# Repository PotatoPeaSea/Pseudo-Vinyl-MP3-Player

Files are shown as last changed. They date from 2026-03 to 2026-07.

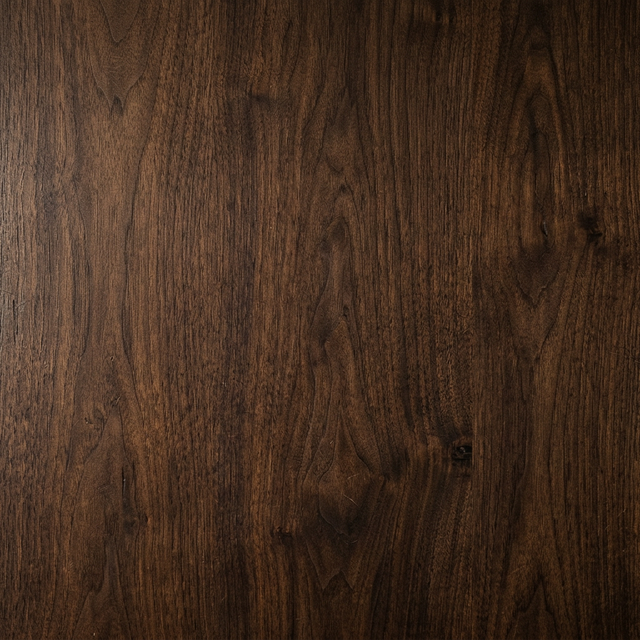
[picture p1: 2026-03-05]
tools/prescale_art/wood_bg.png

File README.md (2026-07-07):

# Pseudo Vinyl MP3 Player

A portable, battery-powered MP3 player built on the **ESP32-WROOM-32** that streams audio wirelessly to Bluetooth earbuds and features a **vinyl-style spinning album art** animation on a circular display.





> [!NOTE]
> **Why the classic ESP32 and not the S3?** The project originally targeted the ESP32-S3, but the S3 only has BLE — **no Bluetooth Classic**, which A2DP audio streaming requires. The original ESP32 is the only chip in the family that can act as an A2DP source. The trade-off is that the WROOM-32 has no PSRAM, which shapes several architecture decisions below.

## Features

- **Bluetooth Audio** — Streams to wireless earbuds/speakers via A2DP (primary output), with on-device scanning, pairing, and auto-reconnect
- **Wired Output** — Secondary 3.5mm headphone jack via PCM5102 I2S DAC, switchable in Settings
- **Circular Display** — 1.28" GC9A01 240×240 IPS round screen
- **Vinyl Spin Animation** — Album art spins like a vinyl record during playback, with a progress ring around the display edge
- **Physical Controls** — 3 buttons (play/pause, next, previous) + rotary encoder (volume/scroll)
- **Shuffle & Repeat** — Normal / Shuffle / Repeat All / Repeat One, cycled via encoder push
- **SD Card Storage** — Recursively scans a FAT32 SD card for MP3s
- **Persistent Settings** — Output mode, volume, and paired Bluetooth device survive power cycles (NVS)
- **Battery Powered** — LiPo battery with TP4056 USB-C charging

## Documentation

| Document | Contents |
|---|---|
| [User Guide](docs/USER_GUIDE.md) | Getting started, controls, pairing, troubleshooting |
| [PRD](docs/PRD.md) | Full requirements, pin assignments, risks |
| This README | System architecture, build instructions |

---

## Hardware

| Component | Model | Interface |
|---|---|---|
| MCU | ESP32-WROOM-32 (4MB flash, no PSRAM) | — |
| DAC | PCM5102 | I2S |
| Display | GC9A01 1.28" Round IPS, 240×240 | SPI (VSPI) |
| Storage | SPI SD card reader, FAT32 | SPI (HSPI) |
| Encoder | KY-040 rotary encoder | GPIO |
| Buttons | 3× tactile switches | GPIO |
| Battery | 3.7V LiPo + TP4056 USB-C charger | — |

### Wiring

Full pin table with rationale lives in the [PRD §5](docs/PRD.md) and [`firmware/src/config.h`](firmware/src/config.h). Summary:

| Peripheral | Pins |
|---|---|
| Display (VSPI) | SCK 18, MOSI 23, CS 5, DC 2, RST 4, BL 19 |
| SD card (HSPI) | SCK 14, MOSI 13, MISO 35, CS 15 |
| PCM5102 (I2S) | BCK 26, LRCK 25, DIN 22 |
| Encoder | CLK 32, DT 33, SW 27 |
| Buttons | Play 16, Next 17, Prev 21 |
| Battery sense | GPIO 34 (ADC1) |

Three wiring rules worth knowing (all enforced by this pin map):

1. **GPIO 12 is deliberately unused.** Many SD modules have pull-ups on every line; a pull-up on GPIO 12 at boot selects 1.8V flash voltage and the board won't boot.
2. **Battery sense must be on ADC1** (GPIO 32–39). ADC2 is unusable while Bluetooth is running.
3. **Display and SD are on separate hardware SPI buses** (VSPI/HSPI), so display refresh never blocks audio streaming from the card.

---

## System Architecture

### Module layout

```
firmware/src/
├── main.cpp                  # Boot sequence + FreeRTOS tasks + input routing
├── config.h                  # All pins, buffer sizes, tunables
├── audio/audio_manager.*     # MP3 decode (helix), playlist, output routing
├── bluetooth/bt_manager.*    # A2DP source, discovery, PCM ring buffer, NVS
├── display/display_manager.* # TFT_eSPI + LVGL glue, draw buffers
├── display/ui_manager.*      # All LVGL screens, virtual keypad, album art
├── input/input_manager.*     # Debounced buttons + quadrature encoder ISR
└── storage/sd_manager.*      # SD mount, recursive MP3 scan, .art loading
```

Each module is a namespace with a small public API (`AudioMgr::`, `BtMgr::`, `UI::`, …); `main.cpp` is the only place that wires them together.

### Task model (dual-core FreeRTOS)

```mermaid
graph LR
    subgraph Core 0
        BT["BT Classic stack<br/>(ESP-IDF tasks)"]
        AUDIO["audio task (prio 3)<br/>SD read → helix MP3 decode<br/>→ volume → output"]
    end
    subgraph Core 1
        UI["ui task (prio 1)<br/>LVGL refresh @ ~60Hz<br/>vinyl spin, BT status sync"]
        INPUT["input task (prio 2)<br/>5ms poll, debounce,<br/>event routing"]
    end
    AUDIO -- "PCM ring buffer (16KB)" --> BT
    INPUT -- "LVGL keys / AudioMgr calls" --> UI
```

- **Audio task (core 0)** runs the decode loop: one `StreamCopy` step per iteration reads MP3 bytes from SD, decodes via helix, applies volume, and writes PCM to the active output. It shares core 0 with the Bluetooth stack on purpose — the 16KB ring buffer between them absorbs scheduling jitter.
- **UI task (core 1)** drives LVGL: syncs now-playing state, spins the vinyl, and polls Bluetooth state a few times per second (not every frame).
- **Input task (core 1)** polls buttons/encoder every 5ms with 50ms debounce and routes events based on the active screen.

### Audio pipeline

```
                         ┌──────────────── audio task ────────────────┐
SD card ──> MP3 file ──> StreamCopy ──> helix MP3 decoder ──> meter ──> VolumeStream ──┐
                                                                                       │ (runtime switch)
                             ┌─────────────────────────────────────────────────────────┤
                             ▼                                                         ▼
                      I2SStream (wired)                                      BtPrint → ring buffer
                             │                                                         │ (pulled by BT task)
                             ▼                                                         ▼
                      PCM5102 DAC → 3.5mm                                    A2DP source → earbuds
```

Key decisions:

- **helix MP3 (arduino-audio-tools)** instead of ESP32-audioI2S: the latter requires PSRAM as of v3.x, which the WROOM-32 doesn't have. Helix decodes in ~30KB of SRAM.
- **Output switching** re-routes the tail of the pipeline at runtime (Settings → Output). Wired mode stops the A2DP source entirely; Bluetooth mode stops the I2S driver.
- **Position/duration** are derived, not parsed: position = decoded PCM bytes ÷ byte rate; duration = position × file size ÷ compressed bytes consumed (exact for CBR, converges fast for VBR).
- **In BT mode with no sink connected, playback holds** rather than racing through the file while writes are dropped.
- A2DP is fixed at 44.1kHz — MP3s at other sample rates play off-speed over Bluetooth (fine on wired).

### Bluetooth design

`BtMgr` wraps `BluetoothA2DPSource` (pschatzmann/ESP32-A2DP):

- While unconnected, the library continuously discovers nearby A2DP sinks; every device seen is collected for the UI list.
- Selecting a device sets it as the **target** — the next discovery hit on that name connects, and the name is persisted to NVS so the player auto-reconnects on later boots.
- The BT stack pulls PCM from the ring buffer on its own task; underruns are zero-filled so the stream never stalls.

### Display & UI

- **TFT_eSPI** drives the GC9A01 at 40MHz on VSPI; **LVGL 8** renders into two 240×30 draw buffers (~14.4KB each) in internal DMA-capable RAM.
- `LV_COLOR_16_SWAP=1` produces SPI byte order directly, so the flush callback pushes pixels without a per-frame swap.
- **Navigation without a touchscreen:** a virtual LVGL *keypad* input device. The input task translates encoder turns into `LV_KEY_NEXT/PREV` (focus movement) and the Play button into `LV_KEY_ENTER` (select) whenever a menu screen is active. Each screen has its own LVGL focus group.
- **Album art** is a pre-scaled raw RGB565 file (`.art`) loaded once per track change, displayed inside a circle-clipped, rotating holder. See the art tool below.

### Memory budget (the no-PSRAM constraint)

Everything must fit in ~320KB of usable internal SRAM:

| Consumer | ~Size |
|---|---|
| BT Classic stack (controller + Bluedroid) | ~150KB |
| LVGL draw buffers (2 × 240×30 px) | 29KB |
| Album art (≤120×120 RGB565, capped) | ≤29KB |
| helix MP3 decoder | ~30KB |
| BT PCM ring buffer | 16KB |
| LVGL widgets, task stacks, everything else | remainder |

This is why art is capped at 120×120 (`ART_MAX_SIDE`) — a full 240×240 frame would be 113KB and simply doesn't fit next to the BT stack. Measured at build: **18.4% static RAM, 52.8% flash**.

---

## Building the Firmware

Requires [PlatformIO](https://platformio.org/).

```bash
cd firmware
pio run                 # build
pio run -t upload       # flash over USB
pio device monitor      # serial log @ 115200
```

The environment is `esp32dev` (see [`firmware/platformio.ini`](firmware/platformio.ini)). Libraries: TFT_eSPI, LVGL 8.3, arduino-audio-tools, arduino-libhelix, ESP32-A2DP. The 3MB `huge_app` partition is used (no OTA) because BT Classic + LVGL + codecs don't fit the default scheme.

## Album Art Pre-Scaler Tool

MP3 album art is prepared on your PC before copying music to the SD card — the device never decodes JPEG/PNG.

```bash
cd tools/prescale_art
pip install -r requirements.txt
python prescale_art.py /path/to/music
```

For each `song.mp3` with embedded art, this writes `song.art` alongside it: a raw 120×120 RGB565 bitmap (28,800 bytes, big-endian to match the firmware's `LV_COLOR_16_SWAP`). A GUI version (`prescale_art_gui.py`) is also available. Files larger than 120×120 are rejected by the firmware.

## Project Structure

```
Pseudo-Vinyl-MP3-Player/
├── README.md                # This file — architecture + build guide
├── docs/
│   ├── PRD.md               # Product Requirements Document
│   └── USER_GUIDE.md        # End-user guide (controls, pairing, troubleshooting)
├── firmware/                # PlatformIO project (ESP32-WROOM-32)
│   ├── platformio.ini
│   └── src/                 # Modules described above
├── tools/
│   └── prescale_art/        # Album art pre-scaler (CLI + GUI)
└── MP3PlayerPCB/            # KiCad PCB design (Phase 3)
```

## License

TBD

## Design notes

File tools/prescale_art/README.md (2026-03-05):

# Album Art Pre-Scaler

Extracts embedded album art from MP3 files, resizes to 240×240 pixels, and converts to **RGB565 raw bitmap** (`.art`) for direct loading on the ESP32-S3 GC9A01 circular display.

## Setup

```bash
cd tools/prescale_art
pip install -r requirements.txt
```

## Usage

```bash
# Basic — process all MP3s in a folder (recursive), output RGB565 .art files
python prescale_art.py /path/to/music

# Force re-process everything (ignore existing .art files)
python prescale_art.py /path/to/music --force

# Output as compressed JPEG instead of raw RGB565
python prescale_art.py /path/to/music --format jpeg --quality 85
```

## Output Formats

| Format | Extension | Size per file | ESP32 Load Time | Notes |
|---|---|---|---|---|
| **RGB565** (default) | `.art` | 115,200 bytes | Fast (no decode) | Raw pixel data, direct DMA to display |
| **JPEG** | `.art.jpg` | ~5-15 KB | Slower (decode needed) | Saves SD card space, requires JPEG decoder on device |

## How It Works

1. Recursively finds all `.mp3` files
2. Extracts the first embedded `APIC` (album art) frame from ID3v2 tags
3. Center-crops to square, then resizes to 240×240 using Lanczos resampling
4. Converts to RGB565 (16-bit, big-endian — matches GC9A01 native byte order)
5. Saves as `<songname>.art` alongside the original MP3
6. Skips files where the `.art` is already newer than the `.mp3`

## File Placement

Place your `.art` files on the SD card **alongside** the MP3s:

```
SD Card/
├── Artist/
│   ├── song1.mp3
│   ├── song1.art      ← generated
│   ├── song2.mp3
│   └── song2.art      ← generated
```

The firmware will look for `<filename>.art` when loading album art for playback.

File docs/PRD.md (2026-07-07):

# Product Requirements Document: ESP32 Portable MP3 Player

**Version:** 3.0  
**Last Updated:** 2026-07-06

> [!NOTE]
> **v3.0 board change:** Moved from ESP32-S3 to the **classic ESP32-WROOM-32**. The S3 has no Bluetooth Classic (BLE only), so the A2DP requirements (§3.4) were unimplementable on it — only the original ESP32 can act as an A2DP source. Trade-off: the WROOM-32 has **no PSRAM**, which drives the memory budget in §4.

---

## 1. Product Overview

A battery-powered, handheld MP3 player built around the **ESP32-WROOM-32**. The device reads MP3 files from an SD card, displays a UI on a circular screen, and primarily streams audio wirelessly via **Bluetooth A2DP** to earbuds/speakers, with a secondary wired output option via the PCM5102 DAC. A signature visual feature is a **vinyl-style spinning album art** animation during playback.

### Development Phases

| Phase | Description |
|---|---|
| **Phase 1 — Prototyping** | Test all modules on an ESP32-WROOM-32 dev board with breadboard wiring |
| **Phase 2 — Firmware** | Develop and stabilize firmware on the dev board |
| **Phase 3 — PCB Design** | Design a custom PCB integrating all components |
| **Phase 4 — Enclosure** | 3D print an enclosure for the final assembly |

---

## 2. Hardware Bill of Materials

| Component | Model | Interface | Key Specs |
|---|---|---|---|
| MCU | ESP32-WROOM-32 | — | Dual-core LX6 @ 240 MHz, **4 MB Flash, no PSRAM**, 520 KB SRAM, **BT Classic (A2DP!)** + BLE + WiFi |
| DAC | PCM5102 | I2S | 32-bit, up to 384 kHz, 112 dB SNR, 3.5 mm jack (secondary output) |
| Display | GC9A01 1.28" Round | SPI | 240×240 px, IPS TFT, 65K color, 3.3V |
| Storage | SPI SD Card Reader | SPI | FAT32, stores MP3 files + pre-scaled album art |
| Input — Dial | KY-040 Rotary Encoder | GPIO (2 data + 1 button) | Quadrature output, integrated push-button |
| Input — Buttons | 3× Tactile Buttons | GPIO | Select/Play, Next, Previous |
| Battery | 3.7V LiPo Cell | — | Capacity TBD based on enclosure size |
| Charger | TP4056 Module | — | 1A USB-C LiPo charging with protection |
| Power Control | SPDT Slide Switch | — | Hard power-off between battery and system |

> [!IMPORTANT]
> **SPI Buses:** The GC9A01 display runs on **VSPI** and the SD card reader on **HSPI** — two independent hardware buses, so no bus-sharing mutex is needed and display refresh can't stall audio reads.

---

## 3. Functional Requirements

### 3.1 Audio Playback

| ID | Requirement | Priority |
|---|---|---|
| AUD-01 | Decode and play MP3 files (CBR and VBR, 128–320 kbps) from SD card | Must |
| AUD-02 | **Default output:** Stream decoded audio via Bluetooth A2DP (SBC codec) to paired wireless earbuds/speakers | Must |
| AUD-03 | **Secondary output:** Output decoded audio via I2S to the PCM5102 DAC for wired 3.5 mm headphone output | Must |
| AUD-04 | User-selectable audio output mode (BT or Wired) via a **Settings menu** option. Bluetooth is default on boot | Must |
| AUD-05 | Support 44.1 kHz / 16-bit stereo as the primary audio format | Must |
| AUD-06 | Gapless playback between tracks | Should |
| AUD-07 | Resume playback from last position after power cycle | Could |

### 3.2 User Interface & Display

| ID | Requirement | Priority |
|---|---|---|
| UI-01 | **Song List Screen:** Scrollable list of songs showing title (from ID3 tag or filename). Menu entries for Bluetooth and Settings at the top | Must |
| UI-02 | **Now Playing Screen:** Song title, artist, and spinning album art. Playback mode indicator (shuffle/repeat) | Must |
| UI-03 | **Vinyl Spin Animation:** Album art rendered as a circle and continuously rotated (~33 RPM) to simulate a spinning record | Must |
| UI-04 | **Bluetooth Menu Screen:** Scan for devices, show available sinks, pair/connect/disconnect | Must |
| UI-05 | **Settings Menu Screen:** Audio output toggle (BT/Wired), and future settings | Must |
| UI-06 | **Volume Indicator:** On-screen overlay that appears when volume is adjusted via encoder | Should |
| UI-07 | **Playback Progress:** Ring around the outer edge of the display showing track progress | Should |
| UI-08 | Smooth transitions between screens (slide or fade) | Could |
| UI-09 | Display should dim/sleep after inactivity to save battery; wake on any input | Should |

### 3.3 Input Controls

| ID | Requirement | Priority |
|---|---|---|
| INP-01 | **Button 1 (Select/Play):** Short press = play/pause on Now Playing, select/enter in menus | Must |
| INP-02 | **Button 2 (Next):** Short press = next track; long press = fast-forward seek | Must |
| INP-03 | **Button 3 (Previous):** Short press = previous track (restart if >3s in); long press = rewind seek | Must |
| INP-04 | **Rotary Encoder Rotation:** Adjust volume (CW = up, CCW = down) on Now Playing; scroll list in menus | Must |
| INP-05 | **Rotary Encoder Push (Now Playing):** Cycle playback mode: Normal → Shuffle → Repeat All → Repeat One → Normal | Must |
| INP-06 | **Rotary Encoder Push (Menus):** Navigate back to previous screen | Must |
| INP-07 | All buttons should be software-debounced (≥30 ms) | Must |

### 3.4 Bluetooth

| ID | Requirement | Priority |
|---|---|---|
| BT-01 | Act as A2DP **Source** — stream audio to Bluetooth headphones/speakers | Must |
| BT-02 | Scan for nearby A2DP sink devices and display results on screen | Must |
| BT-03 | Support pairing and bonding (remember paired devices across reboots via NVS) | Must |
| BT-04 | Auto-reconnect to last paired device on boot (when BT mode is active) | Must |
| BT-05 | AVRCP support (volume sync, play/pause/next/prev remote control from earbuds) | Should |
| BT-06 | Display Bluetooth connection status icon on all screens | Should |

### 3.5 SD Card & File System

| ID | Requirement | Priority |
|---|---|---|
| SD-01 | Read FAT32-formatted SD cards (up to 32 GB) | Must |
| SD-02 | Scan for `.mp3` files recursively in all directories | Must |
| SD-03 | Parse ID3v2 tags for title, artist, album | Must |
| SD-04 | Load **pre-scaled album art** from companion `.art` or `.jpg` files placed alongside MP3s by the desktop tool (see §3.6) | Must |
| SD-05 | Fallback: if no pre-scaled art file exists, display a default/generic album art image | Must |
| SD-06 | Graceful handling of missing/corrupt tags — fall back to filename | Must |
| SD-07 | Support alphabetical and folder-based sorting | Should |
| SD-08 | Cache file list and metadata index to SD card to avoid re-scanning on every boot | Should |

### 3.6 Desktop Album Art Pre-Scaler Tool

| ID | Requirement | Priority |
|---|---|---|
| TOOL-01 | Python CLI tool that processes a directory of MP3 files | Must |
| TOOL-02 | Extract embedded album art (JPEG/PNG) from ID3v2 APIC frames | Must |
| TOOL-03 | Resize and crop to 120×120 pixels (RAM cap on the no-PSRAM WROOM-32), circular mask optional | Must |
| TOOL-04 | Convert to a firmware-friendly format: **RGB565 raw bitmap** (saves JPEG decode on device) or optimized JPEG | Must |
| TOOL-05 | Save output alongside each MP3 with matching filename (e.g., `song.mp3` → `song.art`) | Must |
| TOOL-06 | Skip files that already have an up-to-date `.art` file (based on modification time) | Should |
| TOOL-07 | Support batch processing with progress bar | Should |
| TOOL-08 | Cross-platform: Windows, macOS, Linux | Should |

---

## 4. Non-Functional Requirements

| ID | Requirement | Notes |
|---|---|---|
| NFR-01 | **Memory Budget:** No PSRAM — everything lives in 520 KB internal SRAM alongside the ~150 KB BT Classic stack. Helix MP3 decode (~30 KB), LVGL draw buffers (2×14.4 KB), album art ≤120×120 RGB565 (28.8 KB), BT PCM ring buffer (16 KB) | Critical |
| NFR-02 | **Display Frame Rate:** Vinyl spin animation at ≥20 FPS (target 30) | Smooth visual |
| NFR-03 | **Audio Latency:** ≤200 ms end-to-end (decode → BT output) | Acceptable for music |
| NFR-04 | **Boot Time:** Device ready to play within 5 seconds | User experience |
| NFR-05 | **Battery Life:** Target ≥4 hours continuous BT playback (depends on cell capacity) | Portability |
| NFR-06 | **Debounce Reliability:** No phantom button presses or encoder jitter | Input quality |

---

## 5. System Architecture

```mermaid
graph TD
    BAT["LiPo Battery"] --> SW["Power Switch"]
    SW --> TP["TP4056 Charger"]
    TP --> ESP["ESP32-WROOM-32"]
    SD["SD Card<br/>(SPI)"] -->|MP3 + Art Files| ESP
    ESP -->|I2S Audio| DAC["PCM5102 DAC<br/>→ 3.5mm Jack"]
    ESP -->|BT A2DP| BT["Wireless<br/>Earbuds"]
    ESP -->|SPI| LCD["GC9A01<br/>240×240 Display"]
    BTN["3× Buttons"] -->|GPIO| ESP
    ENC["KY-040 Encoder"] -->|GPIO| ESP
```

### Pin Assignment (Prototype Wiring — ESP32-WROOM-32)

| Signal | GPIO | Notes |
|---|---|---|
| **Display SCK** | GPIO 18 | VSPI, IOMUX-native → 40 MHz |
| **Display MOSI** | GPIO 23 | VSPI |
| **Display CS** | GPIO 5 | GC9A01 chip select |
| **Display DC** | GPIO 2 | Data/command (also onboard LED — harmless) |
| **Display RST** | GPIO 4 | GC9A01 reset |
| **Display BL** | GPIO 19 | Backlight |
| **SD SCK** | GPIO 14 | HSPI |
| **SD MOSI** | GPIO 13 | HSPI |
| **SD MISO** | GPIO 35 | Input-only pin — ideal for MISO |
| **SD CS** | GPIO 15 | SD reader chip select |
| **I2S BCK** | GPIO 26 | To PCM5102 BCK |
| **I2S WS (LRCK)** | GPIO 25 | To PCM5102 LCK |
| **I2S DOUT** | GPIO 22 | To PCM5102 DIN |
| **Encoder CLK** | GPIO 32 | KY-040 clock |
| **Encoder DT** | GPIO 33 | KY-040 data |
| **Encoder SW** | GPIO 27 | KY-040 push button (internal pull-up) |
| **Btn Select/Play** | GPIO 16 | Internal pull-up |
| **Btn Next** | GPIO 17 | Internal pull-up |
| **Btn Previous** | GPIO 21 | Internal pull-up |
| **Battery ADC** | GPIO 34 | **ADC1** — ADC2 is unusable while BT is on |

> [!CAUTION]
> WROOM-32 pin rules: GPIO 6–11 are flash (never use). GPIO 0 is a strapping pin. **GPIO 12 is deliberately unused** — many SD modules have pull-ups on every line, and a pull-up on GPIO 12 at boot selects 1.8 V flash voltage and bricks the boot. GPIO 34/35/36/39 are input-only with no internal pull-ups.

---

## 6. UI/UX Flow

```mermaid
stateDiagram-v2
    [*] --> SongList: Boot
    SongList --> NowPlaying: Select song
    NowPlaying --> SongList: Back (encoder press)
    SongList --> BluetoothMenu: Navigate to BT entry
    BluetoothMenu --> SongList: Back (encoder press)
    SongList --> SettingsMenu: Navigate to Settings entry
    SettingsMenu --> SongList: Back (encoder press)
    NowPlaying --> NowPlaying: Next / Prev track
    NowPlaying --> NowPlaying: Volume (encoder rotate)
    NowPlaying --> NowPlaying: Cycle play mode (encoder press)
```

### Screen Descriptions

1. **Song List** — Vertically scrollable list. Menu entries at top: `⚙ Settings`, `🔵 Bluetooth`. Rotary encoder scrolls, **Select/Play** button enters.
2. **Now Playing** — Circular album art spinning at ~33 RPM. Song title and artist as marquee text. Progress ring around display edge. Playback mode icon (🔀 shuffle, 🔁 repeat all, 🔂 repeat one). Volume overlay on encoder turn.
3. **Bluetooth Menu** — Sub-screens: *Scanning…*, *Device List* (paired devices first), *Connection Status*. Select to pair/connect.
4. **Settings Menu** — Audio Output: `Bluetooth (default)` / `Wired (3.5mm)`. Future: EQ, display brightness, etc.

---

## 7. Risks & Mitigations

| # | Risk | Mitigation |
|---|---|---|
| 1 | **SPI contention** — Display refresh vs. SD reads | Eliminated: display on VSPI, SD on HSPI (independent hardware buses) |
| 2 | **BT + MP3 decode CPU load** — Both are compute-heavy | Audio decode task pinned to Core 0 (with BT stack), UI/input on Core 1; BT sends from a 16 KB PCM ring buffer that absorbs jitter |
| 3 | **Album art too large for RAM** | Desktop pre-scaler outputs ≤120×120 RGB565 (28.8 KB); firmware rejects larger files (`ART_MAX_SIDE`) |
| 4 | **BT A2DP memory overhead** (~150 KB, no PSRAM) | WiFi stack never started; LVGL buffers trimmed to 30 rows; measured static RAM 18.4% at build |
| 5 | **SD card hot-removal** | Detect via card-detect pin (if available) or handle SPI errors gracefully. Pause playback on removal |
| 6 | **Non-44.1 kHz MP3s over BT** — A2DP link is fixed at 44.1 kHz | Files at other sample rates play off-speed on BT (fine on wired). Mitigate by re-encoding, or add a resampler later |

---

## 8. Desktop Album Art Pre-Scaler — Detailed Spec

### Overview
A Python CLI tool that users run on their PC **before loading MP3s onto the SD card**. It extracts embedded album art, resizes to 120×120 (default, configurable with `--size`), and saves in a device-friendly format.

### Usage
```bash
python prescale_art.py /path/to/music/folder
```

### Behavior
1. Recursively walk the input directory for `.mp3` files
2. For each MP3, extract the first `APIC` (attached picture) frame from ID3v2 tags
3. Resize/crop to 120×120 pixels (center-crop if non-square)
4. Convert to **RGB565 raw bitmap** (28,800 bytes, big-endian to match `LV_COLOR_16_SWAP`) — no JPEG decode needed on device
5. Save as `<original_filename>.art` in the same directory
6. Skip if `.art` file exists and is newer than the `.mp3`
7. Print summary: processed / skipped / failed counts

### Dependencies
- `mutagen` — MP3 ID3 tag parsing
- `Pillow` — Image processing
- Python 3.8+

---

## 9. Future Enhancements (Post-MVP)

- **OTA Firmware Updates** via WiFi
- **Battery level indicator** on display (via ADC voltage divider)
- **Equalizer presets** (bass boost, vocal, flat, etc.)
- **Playlist / Favorites** support
- **Sleep timer** — auto-pause after N minutes
- **Light-sleep** power mode when idle

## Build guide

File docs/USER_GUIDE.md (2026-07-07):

# Pseudo Vinyl MP3 Player — User Guide

Everything you need to load music, pair your earbuds, and use the player day-to-day. For build instructions and internals, see the [README](../README.md); for hardware wiring, see the [PRD](PRD.md).

---

## 1. What You Need

- The player (or a breadboard prototype), charged or on USB power
- A **microSD card, formatted FAT32** (up to 32 GB)
- MP3 files (44.1 kHz recommended — see [Tips](#7-tips--limitations))
- Bluetooth earbuds/speaker, **or** wired headphones (3.5mm) if using the DAC output
- A PC with Python for preparing album art (optional but recommended)

---

## 2. Preparing the SD Card

1. **Format** the card as FAT32.
2. **Prepare album art on your PC** (optional). The player can't decode JPEG — art is pre-converted to a device-native format:

   ```bash
   cd tools/prescale_art
   pip install -r requirements.txt
   python prescale_art.py "D:\My Music"
   ```

   For each `song.mp3` with embedded cover art this creates a small `song.art` file next to it. Prefer clicking to typing? Run `prescale_art_gui.py` instead and drop your music folder onto the window.

3. **Copy your music** (the `.mp3` *and* `.art` files together) onto the card. Any folder layout works — the player scans all folders.
4. Insert the card **before powering on**.

> **Upgrading from an older version?** Art files made before July 2026 were 240×240 and are ignored by the current firmware. Re-run the tool with `--force` to regenerate them at the new 120×120 size.

---

## 3. Controls

Three buttons and a rotary encoder. What they do depends on which screen you're on:

### On the Now Playing screen

| Control | Action |
|---|---|
| **Play button** (short press) | Play / pause |
| **Next button** | Next track |
| **Previous button** | Restart track (if >3s in), otherwise previous track |
| **Encoder — rotate** | Volume up / down |
| **Encoder — press** | Cycle play mode: Normal → Shuffle → Repeat All → Repeat One |

### In menus (Library, Settings, Bluetooth)

| Control | Action |
|---|---|
| **Encoder — rotate** | Move the highlight up / down the list |
| **Play button** | Select the highlighted item |
| **Next / Previous buttons** | Switch between screens |
| **Encoder — press** | Go back |

### Screen order

`Next`/`Previous` cycle through the screens in this order:

```
Library  →  Settings  →  Bluetooth  →  Now Playing  →  (back to Library)
```

---

## 4. The Screens

### 🎵 Library (start screen)
A scrollable list of every MP3 found on the card, sorted alphabetically. Songs with album art show a picture icon. Rotate the encoder to browse, press **Play** to start a song — you'll jump to Now Playing.

### 💿 Now Playing
The signature screen: your album art spins like a record at the center, with a gold progress ring around the display edge. Song title and artist scroll below. Top corners show the play mode (left) and volume (right); a small Bluetooth icon appears top-center when connected.

### ⚙ Settings
- **Output: Bluetooth / Wired (3.5mm)** — select to toggle where audio goes. Takes effect immediately (the current song restarts on the new output) and is remembered across power-offs.
- **Bluetooth Devices** — shortcut to the Bluetooth screen.

### 🔵 Bluetooth
Shows connection status and a live list of discovered audio devices. See the next section.

---

## 5. Pairing Bluetooth Earbuds

1. Make sure **Output: Bluetooth** is set in Settings (it's the factory default).
2. Put your earbuds/speaker in **pairing mode**.
3. Go to the **Bluetooth** screen. The player scans continuously — nearby devices appear in the list within a few seconds ("Searching…" shows while the list is empty).
4. Rotate the encoder to highlight your device and press **Play** to select it. The status line shows "Connecting…", then "Connected".
5. Play a song. Audio now streams to your earbuds.

**Auto-reconnect:** the player remembers your device and reconnects to it automatically on every boot — you only pair once. To switch to different earbuds, just pick another device from the Bluetooth list.

**No sink connected?** In Bluetooth mode, playback politely waits (it won't silently burn through your playlist) until a device connects.

---

## 6. Wired Listening

1. Plug headphones into the 3.5mm jack.
2. Settings → **Output** → select until it reads **Wired (3.5mm)**.

Bluetooth switches off entirely in wired mode (saves battery). Switch back the same way.

---

## 7. Tips & Limitations

- **Use 44.1 kHz MP3s for Bluetooth.** The BT link runs at a fixed 44.1 kHz; files at 48 kHz or other rates will play slightly fast/slow over Bluetooth (wired output is unaffected). Most music files are already 44.1 kHz.
- **CBR files show exact durations.** VBR files show an estimate that refines itself during the first seconds of playback.
- **Volume is remembered**, as are output mode and your paired device.
- **Album art without the tool:** songs without an `.art` file show a gold record label instead — everything else works normally.

---

## 8. Charging & Power

- Charge via the **USB-C** port (TP4056, ~1A). Charging works while powered off.
- The **slide switch** hard-disconnects the battery — use it for storage or transport.
- Battery life target is ≥4 hours of Bluetooth playback (depends on the cell fitted).

---

## 9. Troubleshooting

| Symptom | Likely cause / fix |
|---|---|
| **"No SD card!" on boot / empty Library** | Card not FAT32, not inserted fully, or inserted after boot. Power-cycle with the card in. |
| **Board won't boot at all with SD module wired** | If your SD module has a pull-up wired to GPIO 12 — it must not be connected there. See PRD pin rules. |
| **My earbuds never appear in the list** | Make sure they're in *pairing* mode (not just on), and close to the player. Some devices only advertise for ~60s — re-enter pairing mode. |
| **Connected, but no sound** | Check a song is actually playing (Now Playing shows the spinning record) and volume isn't at 0. |
| **Music sounds too fast/slow on Bluetooth** | The file isn't 44.1 kHz. Re-encode it, or use wired output. |
| **Songs play but art shows a plain gold label** | No `.art` file next to the MP3, or an old 240×240 art file. Re-run the pre-scaler tool (`--force` to regenerate). |
| **Playback "frozen" in BT mode** | No sink connected — playback holds until your earbuds connect (or switch to Wired in Settings). |
| **Wrong/garbled colors on screen** | SPI wiring issue on the display (check MOSI/SCK/DC), or a firmware build older than July 2026. |
| **Volume knob scrolls instead of changing volume** | You're on a menu screen — volume control is on Now Playing only. |

Still stuck? Connect USB and open a serial monitor at **115200 baud** — the firmware logs every boot step (`[SD]`, `[BT]`, `[Audio]`, `[UI]`) and most failures are named explicitly there.

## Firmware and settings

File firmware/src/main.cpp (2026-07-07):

/**
 * Pseudo Vinyl MP3 Player — Firmware
 * Board: ESP32-WROOM-32 (classic ESP32, BT Classic A2DP source)
 *
 * Entry point: initializes all peripherals and spawns FreeRTOS tasks.
 *
 * Task layout (dual-core):
 *   Core 0: audio_task   — MP3 decode + output feed (BT stack also lives here)
 *   Core 1: ui_task      — LVGL display refresh (~60fps)
 *   Core 1: input_task   — Button/encoder polling (5ms)
 *
 * Controls:
 *   Now Playing: PLAY=play/pause, NEXT/PREV=track, encoder=volume,
 *                encoder press=cycle play mode
 *   Menus:       encoder=move focus, PLAY=select, NEXT/PREV=switch screen,
 *                encoder press=back
 */

#include <Arduino.h>
#include <lvgl.h>   // LV_KEY_* codes for UI::sendKey
#include "config.h"
#include "display/display_manager.h"
#include "display/ui_manager.h"
#include "input/input_manager.h"
#include "storage/sd_manager.h"
#include "audio/audio_manager.h"
#include "bluetooth/bt_manager.h"

// ── Task Handles ────────────────────────────────────────────
static TaskHandle_t audioTaskHandle = nullptr;
static TaskHandle_t uiTaskHandle = nullptr;
static TaskHandle_t inputTaskHandle = nullptr;

// ── Song library (shared state) ─────────────────────────────
static std::vector<SongInfo> songs;

// ═══════════════════════════════════════════════════════════
// AUDIO TASK (Core 0) — MP3 decode + output feed
// ═══════════════════════════════════════════════════════════
void audioTask(void *param) {
    Serial.println("[Task] Audio task started on Core 0");

    for (;;) {
        AudioMgr::loop();
        vTaskDelay(pdMS_TO_TICKS(1));   // Yield briefly
    }
}

// ═══════════════════════════════════════════════════════════
// UI TASK (Core 1) — LVGL refresh + state sync
// ═══════════════════════════════════════════════════════════
void uiTask(void *param) {
    Serial.println("[Task] UI task started on Core 1");

    bool lastBtConnected = false;
    uint32_t lastBtPoll = 0;

    for (;;) {
        // Update now-playing info
        const SongInfo *current = AudioMgr::currentSong();
        UI::setNowPlaying(current, AudioMgr::isPlaying());
        UI::setProgress(AudioMgr::positionSec(), AudioMgr::durationSec());
        UI::setVolume(AudioMgr::getVolume(), MAX_VOLUME);
        UI::setPlayModeIndicator(AudioMgr::getPlayMode());

        // Bluetooth state → UI (poll a few times a second, not every frame)
        uint32_t now = millis();
        if (now - lastBtPoll > 250) {
            lastBtPoll = now;

            if (BtMgr::scanListChanged()) {
                UI::setBtDevices(BtMgr::scanResults());
            }

            bool conn = BtMgr::isConnected();
            if (conn != lastBtConnected) {
                lastBtConnected = conn;
                UI::setBtStatus(conn ? ("Connected: " + BtMgr::connectedName())
                                     : (BtMgr::isStarted() ? "Searching..." : "Off (wired mode)"));
            }
        }

        // Spin vinyl + LVGL timers
        UI::update();
        Display::update();

        vTaskDelay(pdMS_TO_TICKS(UI_REFRESH_MS));
    }
}

// ═══════════════════════════════════════════════════════════
// INPUT TASK (Core 1) — Buttons + encoder → events
// ═══════════════════════════════════════════════════════════
static void handleMenuScreenCycle(bool forward) {
    // Menu screen order: SONG_LIST → SETTINGS → BLUETOOTH → NOW_PLAYING
    static const Screen order[] = {
        Screen::SONG_LIST, Screen::SETTINGS, Screen::BLUETOOTH, Screen::NOW_PLAYING
    };
    Screen cur = UI::activeScreen();
    int idx = 0;
    for (int i = 0; i < 4; i++) {
        if (order[i] == cur) { idx = i; break; }
    }
    idx = (idx + (forward ? 1 : 3)) % 4;
    UI::showScreen(order[idx]);
}

void inputTask(void *param) {
    Serial.println("[Task] Input task started on Core 1");

    for (;;) {
        Input::poll();

        while (Input::hasEvent()) {
            InputEvent evt = Input::getEvent();
            Screen screen = UI::activeScreen();
            bool onNowPlaying = (screen == Screen::NOW_PLAYING);

            switch (evt) {
                case InputEvent::BTN_PLAY:
                    if (onNowPlaying) {
                        if (AudioMgr::isPlaying()) {
                            AudioMgr::pause();
                        } else if (AudioMgr::currentIndex() >= 0) {
                            AudioMgr::resume();
                        } else if (!songs.empty()) {
                            AudioMgr::play(0);
                        }
                    } else {
                        // Select focused item in menus
                        UI::sendKey(LV_KEY_ENTER);
                    }
                    break;

                case InputEvent::BTN_NEXT:
                    if (onNowPlaying) {
                        AudioMgr::next();
                    } else {
                        handleMenuScreenCycle(true);
                    }
                    break;

                case InputEvent::BTN_PREV:
                    if (onNowPlaying) {
                        AudioMgr::prev();
                    } else {
                        handleMenuScreenCycle(false);
                    }
                    break;

                case InputEvent::ENC_CW:
                    if (onNowPlaying) {
                        AudioMgr::setVolume(AudioMgr::getVolume() + 1);
                    } else {
                        UI::sendKey(LV_KEY_NEXT);
                    }
                    break;

                case InputEvent::ENC_CCW:
                    if (onNowPlaying) {
                        AudioMgr::setVolume(AudioMgr::getVolume() - 1);
                    } else {
                        UI::sendKey(LV_KEY_PREV);
                    }
                    break;

                case InputEvent::ENC_PRESS:
                    if (onNowPlaying) {
                        AudioMgr::cyclePlayMode();
                    } else if (screen == Screen::SONG_LIST) {
                        UI::showScreen(Screen::NOW_PLAYING);
                    } else {
                        // Back to song list from Settings/Bluetooth
                        UI::showScreen(Screen::SONG_LIST);
                    }
                    break;

                default:
                    break;
            }
        }

        vTaskDelay(pdMS_TO_TICKS(INPUT_POLL_MS));
    }
}

// ═══════════════════════════════════════════════════════════
// ARDUINO ENTRY POINTS
// ═══════════════════════════════════════════════════════════

void setup() {
    Serial.begin(115200);
    delay(500);
    Serial.println("\n═══════════════════════════════════");
    Serial.println("  Pseudo Vinyl MP3 Player v2.0");
    Serial.println("  ESP32-WROOM-32 + A2DP");
    Serial.println("═══════════════════════════════════\n");

    // 1. Display
    Display::init();
    UI::init();
    Serial.println("[Boot] Display ready");

    // 2. SD Card
    if (Storage::init()) {
        songs = Storage::scanMusic("/");
        AudioMgr::setPlaylist(songs);
        UI::setSongList(songs);
        Serial.printf("[Boot] %d songs loaded\n", songs.size());
    } else {
        Serial.println("[Boot] WARNING: No SD card!");
    }

    // 3. Input
    Input::init();

    // 4. Bluetooth (target device from NVS) + audio pipeline.
    //    AudioMgr::init starts A2DP if the saved output mode is Bluetooth.
    BtMgr::init();
    AudioMgr::init();
    UI::setOutputModeLabel(AudioMgr::getOutputMode());
    UI::setBtStatus(BtMgr::isStarted() ? "Searching..." : "Off (wired mode)");

    // 5. Spawn FreeRTOS tasks
    xTaskCreatePinnedToCore(audioTask, "audio", 8192, nullptr, 3, &audioTaskHandle, 0);
    xTaskCreatePinnedToCore(uiTask,    "ui",    8192, nullptr, 1, &uiTaskHandle,    1);
    xTaskCreatePinnedToCore(inputTask, "input", 4096, nullptr, 2, &inputTaskHandle, 1);

    Serial.println("[Boot] All tasks launched\n");
}

void loop() {
    // All work is done in FreeRTOS tasks
    vTaskDelay(pdMS_TO_TICKS(1000));
}

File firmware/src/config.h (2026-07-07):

#pragma once
/**
 * Pseudo Vinyl MP3 Player — Hardware Configuration
 * Board: ESP32-WROOM-32 (classic ESP32, 4MB flash, no PSRAM)
 *
 * Pin rules for this chip:
 *  - GPIO 6-11 are flash — never use
 *  - GPIO 0 is a strapping pin — avoid
 *  - GPIO 12 (MTDI) strapping: a pull-up at boot bricks flash voltage —
 *    left unused because many SD modules have pull-ups on all lines
 *  - GPIO 34/35/36/39 are INPUT-ONLY, no internal pull-ups
 *  - ADC2 pins can't do analogRead while Bluetooth is on → battery on ADC1
 */

// ── Feature Flags ───────────────────────────────────────────
#ifndef BT_ENABLED
#define BT_ENABLED          1
#endif

// ── Display: GC9A01 (240×240 round IPS, VSPI) ───────────────
// NOTE: pins are duplicated in platformio.ini TFT_eSPI build flags —
// keep both in sync!
#define DISPLAY_WIDTH       240
#define DISPLAY_HEIGHT      240
#define PIN_TFT_MOSI        23
#define PIN_TFT_SCLK        18
#define PIN_TFT_CS          5
#define PIN_TFT_DC          2
#define PIN_TFT_RST         4
#define PIN_TFT_BL          19

// ── SD Card (HSPI) ──────────────────────────────────────────
// MISO on input-only GPIO 35 (SD module drives it; no pull-up needed here)
#define PIN_SD_SCLK         14
#define PIN_SD_MOSI         13
#define PIN_SD_MISO         35
#define PIN_SD_CS           15

// ── Audio: PCM5102 DAC (I2S, wired output) ──────────────────
#define PIN_I2S_BCLK        26
#define PIN_I2S_LRCK        25
#define PIN_I2S_DOUT        22

// ── Rotary Encoder (KY-040) ─────────────────────────────────
#define PIN_ENC_A           32
#define PIN_ENC_B           33
#define PIN_ENC_SW          27

// ── Buttons ─────────────────────────────────────────────────
#define PIN_BTN_PLAY        16
#define PIN_BTN_NEXT        17
#define PIN_BTN_PREV        21

// ── Battery voltage divider (ADC1_CH6 — usable with BT on) ──
#define PIN_BATT_ADC        34

// ── Bluetooth ───────────────────────────────────────────────
#define BT_DEVICE_NAME      "Pseudo Vinyl"
#define BT_RINGBUF_BYTES    (16 * 1024)   // ~92ms of 44.1k stereo PCM

// ── Audio Defaults ──────────────────────────────────────────
#define DEFAULT_VOLUME      12      // 0-21
#define MAX_VOLUME          21

// ── Album Art ───────────────────────────────────────────────
// No PSRAM: 240×240 RGB565 (113KB) doesn't fit next to the BT stack.
// Art files are ≤120×120 RGB565 (28.8KB), scaled onto the 90px vinyl label.
#define ART_MAX_SIDE        120
#define ART_MAX_BYTES       (ART_MAX_SIDE * ART_MAX_SIDE * 2)

// ── UI Constants ────────────────────────────────────────────
#define VINYL_SPIN_SPEED_DEG 2       // Degrees per frame
#define UI_REFRESH_MS        16      // ~60fps LVGL tick
#define INPUT_POLL_MS        5       // Button/encoder poll interval
#define DEBOUNCE_MS          50      // Button debounce

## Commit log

2026-07-07 Port firmware to ESP32-WROOM-32 for Bluetooth A2DP support
    The ESP32-S3 has no Bluetooth Classic, so the A2DP requirements were
    unimplementable on it — only the original ESP32 can be an A2DP source.
    The trade-off is no PSRAM, which drives most of the changes below.
    Firmware:
    - Replace ESP32-audioI2S (requires PSRAM as of v3.x) with helix MP3
    decode via arduino-audio-tools; output switches at runtime between
    wired I2S (PCM5102) and Bluetooth
    - Add bt_manager: A2DP source with on-device scanning, pairing, and
    NVS-persisted auto-reconnect, fed through a 16KB PCM ring buffer
    - New WROOM-32 pin map (avoids GPIO 12 strap hazard, battery on ADC1)
    - Add LVGL keypad indev so lists are naviga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
    [MP3PlayerPCB.kicad_pcb, MP3PlayerPCB.kicad_sch]
2026-07-28 - finished schematic for PCB, including all buttons, power management, and connectors.
    - May need to add LDO, will confirm after double checking hardware
    - Still need to add some footprints
    [MP3PlayerPCB.kicad_sch]
2026-07-30 Added all foot prints and routed most of the PCB, will have to do some more hardware verification before PCB if finalized
    [MP3PlayerPCB.kicad_sch]
2026-10-18 Add enclosure CAD, renders and schematic to the README
    Bring CAD/ (Fusion 360 assembly and STLs) over from feature/wrover-n4r8
    so master has the enclosure source, and add rendered views of the
    enclosure and the KiCad schematic under docs/images/.
2026-11-04 Retarget firmware to ESP32-WROVER N4R8, add PCB v2 and Spotify Sync tool (#1)
    - Firmware: retarget to ESP32-WROVER N4R8 (new pin map, PSRAM, SDMMC 1-bit SD, display on new SPI pins), display panel sleep after idle, bring-up/pin/display test modes, RAM-squeeze and A2DP stall fixes, Now Playing fixes, library-at-boot and folder playlists.
    - Tools: Spotify Sync tab for the desktop art/prescale toolkit.
    - Hardware: new MP3PlayerPCB_v2 KiCad project (ESP32-CAM carrier, PCF8574 input expander, AP2112K, GC9A01 header), routed 2-layer.
    - Renders: regenerated v2 PCB and schematic renders; regenerated v1 schematic image.
